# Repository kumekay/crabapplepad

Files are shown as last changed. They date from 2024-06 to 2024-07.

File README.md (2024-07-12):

# crabapplepad v2

Wireless minimalistic foldable split keyboard

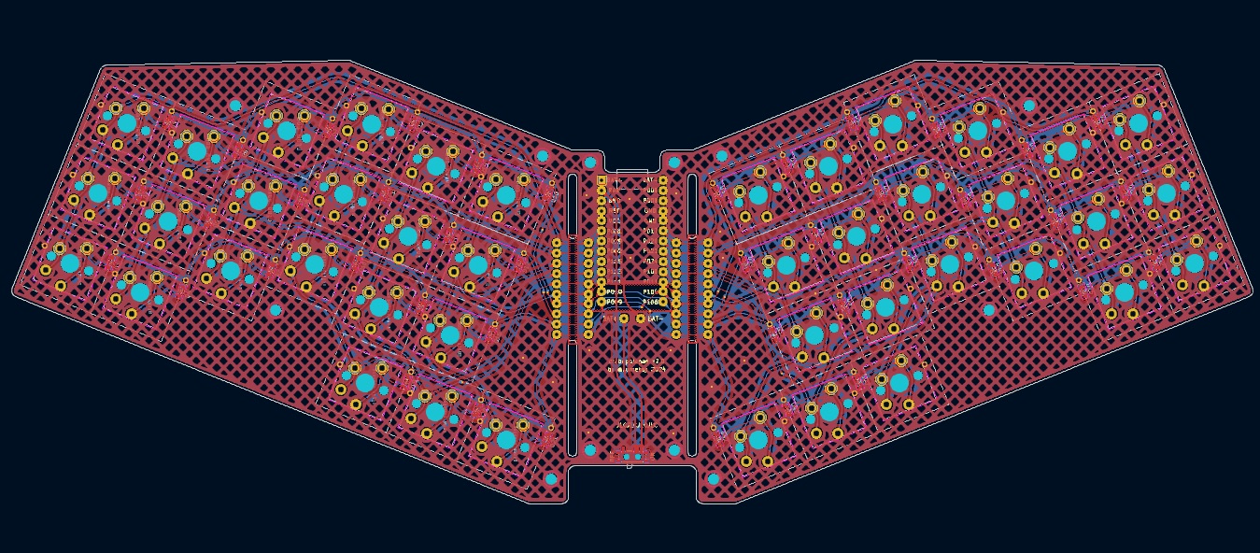
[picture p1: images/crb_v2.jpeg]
crabapplepad v2


## Features

- Supports Kailh Choc and MX switches
- Optionally foldable with Choc switches
- Minimalistic. No LEDs, no RGB, no extra keys
- With Kailh Choc it's 3cm thick in the folded state
- Split. The two halves are connected with a 3d printed hinge
- Wireless. Uses Nice!Nano or ProMicro nRF52840 with BLE
- 42 keys (I use Cyrillic layout too and 36 keys is not enough)
- Apple Magic Trackpad can be magnetically attached (optional)

## PCB design

PCB is generated using [ergogen](https://github.com/ergogen/ergogen). Then it finished in KiCAD.
To regenerate the PCB run:

```bash
npx ergogen . --clean && open output/pcbs/kbd.kicad_pcb
```

NB! The final PCB was heavily modified in KiCAD

## Firmware

The firmware is based on [ZMK](https://zmkfirmware.dev/) and [Myrioku Layout](https://github.com/manna-harbour/miryoku) adapted for 42 keys. T

## Where is the slim V1?

It's in the [v1](https://github.com/kumekay/crabapplepad/tree/v1) branch. The V1 is ccm thick in the folded state with Kailh X switches. The V2 is 3cm thick with Kailh Choc switches.

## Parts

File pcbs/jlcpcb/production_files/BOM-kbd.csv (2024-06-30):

Comment | Designator | Footprint | LCSC
SW_MX_Choc_PCB_1.00u | S42 | SW_Cherry_MX_Choc_PCB_1.00u_nosilk
SW_MX_Choc_PCB_1.00u | S37 | SW_Cherry_MX_Choc_PCB_1.00u_nosilk
SW_MX_Choc_PCB_1.00u | S14 | SW_Cherry_MX_Choc_PCB_1.00u_nosilk
SW_MX_Choc_PCB_1.00u | S8 | SW_Cherry_MX_Choc_PCB_1.00u_nosilk
SW_MX_Choc_PCB_1.00u | S4 | SW_Cherry_MX_Choc_PCB_1.00u_nosilk
SW_MX_Choc_PCB_1.00u | S16 | SW_Cherry_MX_Choc_PCB_1.00u_nosilk
SW_MX_Choc_PCB_1.00u | S6 | SW_Cherry_MX_Choc_PCB_1.00u_nosilk
SW_MX_Choc_PCB_1.00u | S26 | SW_Cherry_MX_Choc_PCB_1.00u_nosilk
SW_MX_Choc_PCB_1.00u | S20 | SW_Cherry_MX_Choc_PCB_1.00u_nosilk
SW_MX_Choc_PCB_1.00u | S15 | SW_Cherry_MX_Choc_PCB_1.00u_nosilk
SW_MX_Choc_PCB_1.00u | S17 | SW_Cherry_MX_Choc_PCB_1.00u_nosilk
SW_MX_Choc_PCB_1.00u | S29 | SW_Cherry_MX_Choc_PCB_1.00u_nosilk
SW_MX_Choc_PCB_1.00u | S21 | SW_Cherry_MX_Choc_PCB_1.00u_nosilk
SW_MX_Choc_PCB_1.00u | S31 | SW_Cherry_MX_Choc_PCB_1.00u_nosilk
SW_MX_Choc_PCB_1.00u | S12 | SW_Cherry_MX_Choc_PCB_1.00u_nosilk
SW_MX_Choc_PCB_1.00u | S25 | SW_Cherry_MX_Choc_PCB_1.00u_nosilk
SW_MX_Choc_PCB_1.00u | S13 | SW_Cherry_MX_Choc_PCB_1.00u_nosilk
SW_MX_Choc_PCB_1.00u | S34 | SW_Cherry_MX_Choc_PCB_1.00u_nosilk
SW_MX_Choc_PCB_1.00u | S23 | SW_Cherry_MX_Choc_PCB_1.00u_nosilk
SW_MX_Choc_PCB_1.00u | S7 | SW_Cherry_MX_Choc_PCB_1.00u_nosilk
SW_MX_Choc_PCB_1.00u | S11 | SW_Cherry_MX_Choc_PCB_1.00u_nosilk
SW_MX_Choc_PCB_1.00u | S24 | SW_Cherry_MX_Choc_PCB_1.00u_nosilk
SW_MX_Choc_PCB_1.00u | S39 | SW_Cherry_MX_Choc_PCB_1.00u_nosilk
SW_MX_Choc_PCB_1.00u | S10 | SW_Cherry_MX_Choc_PCB_1.00u_nosilk
SW_MX_Choc_PCB_1.00u | S35 | SW_Cherry_MX_Choc_PCB_1.00u_nosilk
SW_MX_Choc_PCB_1.00u | S2 | SW_Cherry_MX_Choc_PCB_1.00u_nosilk
SW_MX_Choc_PCB_1.00u | S18 | SW_Cherry_MX_Choc_PCB_1.00u_nosilk
SW_MX_Choc_PCB_1.00u | S36 | SW_Cherry_MX_Choc_PCB_1.00u_nosilk
SW_MX_Choc_PCB_1.00u | S1 | SW_Cherry_MX_Choc_PCB_1.00u_nosilk
SW_MX_Choc_PCB_1.00u | S28 | SW_Cherry_MX_Choc_PCB_1.00u_nosilk
SW_MX_Choc_PCB_1.00u | S3 | SW_Cherry_MX_Choc_PCB_1.00u_nosilk
SW_MX_Choc_PCB_1.00u | S19 | SW_Cherry_MX_Choc_PCB_1.00u_nosilk
SW_MX_Choc_PCB_1.00u | S33 | SW_Cherry_MX_Choc_PCB_1.00u_nosilk
SW_MX_Choc_PCB_1.00u | S9 | SW_Cherry_MX_Choc_PCB_1.00u_nosilk
SW_MX_Choc_PCB_1.00u | S30 | SW_Cherry_MX_Choc_PCB_1.00u_nosilk
SW_MX_Choc_PCB_1.00u | S40 | SW_Cherry_MX_Choc_PCB_1.00u_nosilk
SW_MX_Choc_PCB_1.00u | S41 | SW_Cherry_MX_Choc_PCB_1.00u_nosilk
SW_MX_Choc_PCB_1.00u | S32 | SW_Cherry_MX_Choc_PCB_1.00u_nosilk
SW_MX_Choc_PCB_1.00u | S27 | SW_Cherry_MX_Choc_PCB_1.00u_nosilk
SW_MX_Choc_PCB_1.00u | S38 | SW_Cherry_MX_Choc_PCB_1.00u_nosilk
SW_MX_Choc_PCB_1.00u | S22 | SW_Cherry_MX_Choc_PCB_1.00u_nosilk
SW_MX_Choc_PCB_1.00u | S5 | SW_Cherry_MX_Choc_PCB_1.00u_nosilk
 | D15 | D_SOD-323_HandSoldering
 | D30 | D_SOD-323_HandSoldering
 | D3 | D_SOD-323_HandSoldering
 | D5 | D_SOD-323_HandSoldering
 | D18 | D_SOD-323_HandSoldering
 | D13 | D_SOD-323_HandSoldering
 | D17 | D_SOD-323_HandSoldering
 | D28 | D_SOD-323_HandSoldering
 | D35 | D_SOD-323_HandSoldering
 | D39 | D_SOD-323_HandSoldering
 | D27 | D_SOD-323_HandSoldering
 | D11 | D_SOD-323_HandSoldering
 | D41 | D_SOD-323_HandSoldering
 | D25 | D_SOD-323_HandSoldering
 | D23 | D_SOD-323_HandSoldering
 | D32 | D_SOD-323_HandSoldering
 | D20 | D_SOD-323_HandSoldering
 | MCU1 | ProMicro
 | D14 | D_SOD-323_HandSoldering
 | D40 | D_SOD-323_HandSoldering
 | D21 | D_SOD-323_HandSoldering
 | D7 | D_SOD-323_HandSoldering
 | D16 | D_SOD-323_HandSoldering
 | D1 | D_SOD-323_HandSoldering
 | D31 | D_SOD-323_HandSoldering
 | D6 | D_SOD-323_HandSoldering
 | D42 | D_SOD-323_HandSoldering
 | D29 | D_SOD-323_HandSoldering
 | D10 | D_SOD-323_HandSoldering
 | D8 | D_SOD-323_HandSoldering
 | D26 | D_SOD-323_HandSoldering
 | D24 | D_SOD-323_HandSoldering
 | D2 | D_SOD-323_HandSoldering
 | D4 | D_SOD-323_HandSoldering
 | D19 | D_SOD-323_HandSoldering
 | D22 | D_SOD-323_HandSoldering
 | D37 | D_SOD-323_HandSoldering
 | D36 | D_SOD-323_HandSoldering
 | D33 | D_SOD-323_HandSoldering
 | D12 | D_SOD-323_HandSoldering
 | D9 | D_SOD-323_HandSoldering
 | D34 | D_SOD-323_HandSoldering
 | D38 | D_SOD-323_HandSoldering

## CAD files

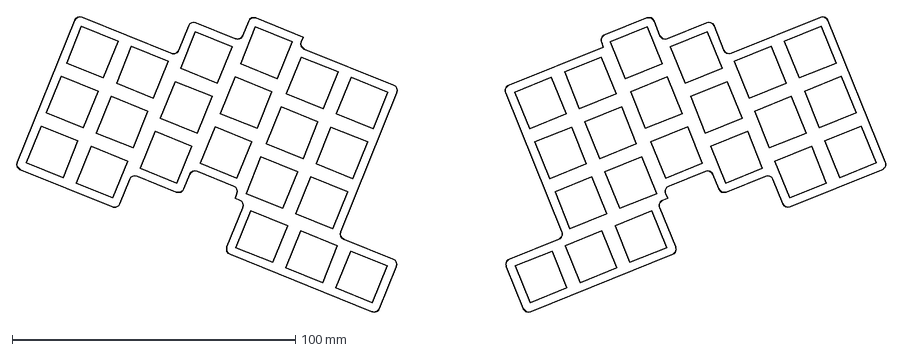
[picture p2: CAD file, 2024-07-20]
outlines/key_holder_choc.dxf
307.0 x 104.7 mm

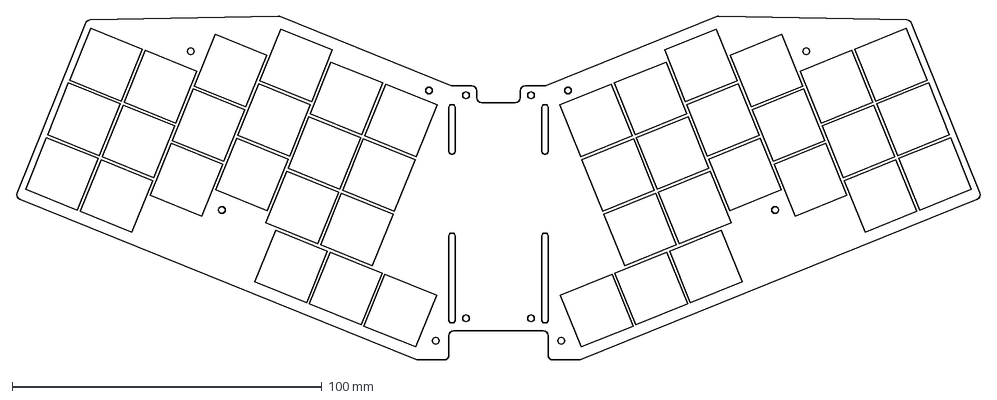
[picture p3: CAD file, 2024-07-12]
outlines/combo.dxf
311.4 x 111.0 mm

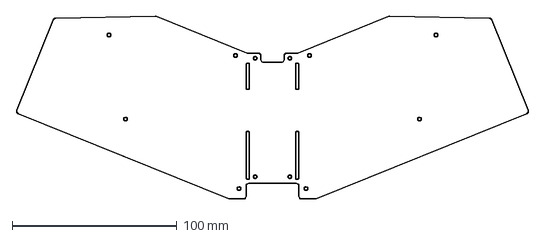
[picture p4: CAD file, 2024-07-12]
outlines/board.dxf
311.4 x 111.0 mm

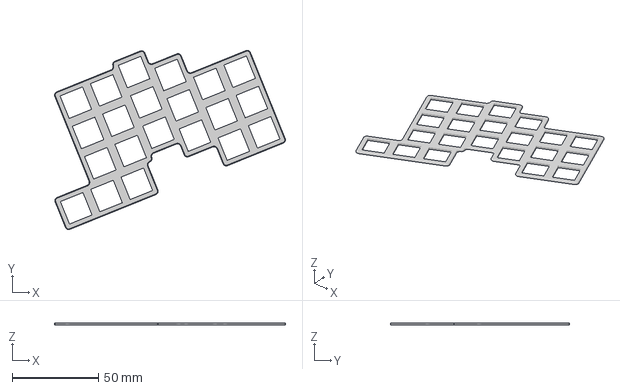
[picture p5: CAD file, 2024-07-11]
outlines/Key holder.3mf
134.3 x 104.2 x 1.40 mm

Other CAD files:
outlines/key_holder.dxf

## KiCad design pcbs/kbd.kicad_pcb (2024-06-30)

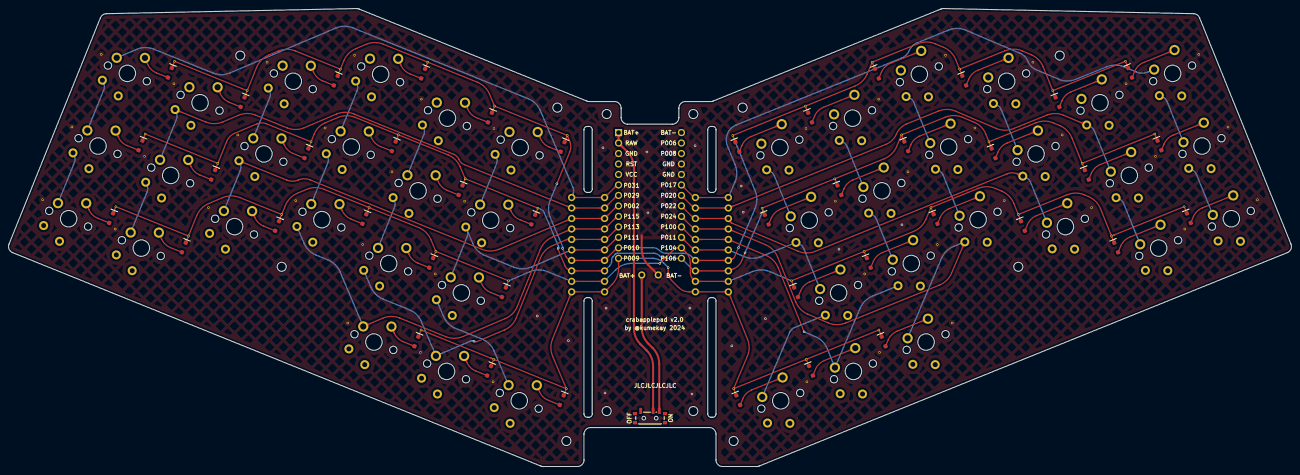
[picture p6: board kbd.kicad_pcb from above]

Board: 2 copper layers, 311.0 x 111.0 mm, 98 parts (0 on the bottom side), 60 nets.

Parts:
D1, D2, D3, D4, D5, D6, D7, D8, D9, D10, D11, D12, D13, D14, D15, D16, D17, D18, D19, D20, D21, D22, D23, D24, D25, D26, D27, D28, D29, D30, D31, D32, D33, D34, D35, D36, D37, D38, D39, D40, D41, D42: D_SOD-323_HandSoldering
MCU1: ProMicro
PWR1: power_switch_smd_side
S1, S2, S3, S4, S5, S6, S7, S8, S9, S10, S11, S12, S13, S14, S15, S16, S17, S18, S19, S20, S21, S22, S23, S24, S25, S26, S27, S28, S29, S30, S31, S32, S33, S34, S35, S36, S37, S38, S39, S40, S41, S42: SW_MX_Choc_PCB_1.00u; SW_Cherry_MX_Choc_PCB_1.00u_nosilk
_129, _130, _131, _132, _133, _134, _135, _136, _137, _138, _139, _140: MountingHole_2.2mm_M2_DIN965

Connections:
GND: MCU1.3, MCU1.14, MCU1.17, MCU1.18
P002: MCU1.8, S7.1, S8.1, S9.1
P009: D19.1, D20.1, D21.1, D40.1, D41.1, D42.1, MCU1.13
P010: D3.1, D6.1, D9.1, D12.1, D15.1, D18.1, D24.1, D27.1, D30.1, D33.1, D36.1, D39.1, MCU1.12
P011: MCU1.24, S37.1, S38.1, S39.1, S42.1
P017: MCU1.19, S22.1, S23.1, S24.1
P020: MCU1.20, S25.1, S26.1, S27.1
P022: MCU1.21, S28.1, S29.1, S30.1
P024: MCU1.22, S31.1, S32.1, S33.1, S40.1
P029: MCU1.7, S4.1, S5.1, S6.1
P031: MCU1.6, S1.1, S2.1, S3.1
P100: MCU1.23, S34.1, S35.1, S36.1, S41.1
P104: D1.1, D4.1, D7.1, D10.1, D13.1, D16.1, D22.1, D25.1, D28.1, D31.1, D34.1, D37.1, MCU1.25
P106: D2.1, D5.1, D8.1, D11.1, D14.1, D17.1, D23.1, D26.1, D29.1, D32.1, D35.1, D38.1, MCU1.26
P111: MCU1.11, S16.1, S17.1, S18.1, S21.1
P113: MCU1.10, S13.1, S14.1, S15.1, S20.1
P115: MCU1.9, S10.1, S11.1, S12.1, S19.1
RAW: MCU1.1, MCU1.2, PWR1.2
alpha_cluster: D19.2, S19.2
beta_cluster: D20.2, S20.2
gamma_cluster: D21.2, S21.2
index_bottom: D13.2, S13.2
index_home: D14.2, S14.2
index_top: D15.2, S15.2
inner_bottom: D16.2, S16.2
inner_home: D17.2, S17.2
inner_top: D18.2, S18.2
middle_bottom: D10.2, S10.2
middle_home: D11.2, S11.2
middle_top: D12.2, S12.2
mirror_alpha_cluster: D40.2, S40.2
mirror_beta_cluster: D41.2, S41.2
mirror_gamma_cluster: D42.2, S42.2
mirror_index_bottom: D34.2, S34.2
mirror_index_home: D35.2, S35.2
mirror_index_top: D36.2, S36.2
mirror_inner_bottom: D37.2, S37.2
mirror_inner_home: D38.2, S38.2
mirror_inner_top: D39.2, S39.2
mirror_middle_bottom: D31.2, S31.2
mirror_middle_home: D32.2, S32.2
mirror_middle_top: D33.2, S33.2
mirror_outer_bottom: D22.2, S22.2
mirror_outer_home: D23.2, S23.2
mirror_outer_top: D24.2, S24.2
mirror_pinky_bottom: D25.2, S25.2
mirror_pinky_home: D26.2, S26.2
mirror_pinky_top: D27.2, S27.2
mirror_ring_bottom: D28.2, S28.2
mirror_ring_home: D29.2, S29.2
mirror_ring_top: D30.2, S30.2
outer_bottom: D1.2, S1.2
outer_home: D2.2, S2.2
outer_top: D3.2, S3.2
pinky_bottom: D4.2, S4.2
pinky_home: D5.2, S5.2
pinky_top: D6.2, S6.2
ring_bottom: D7.2, S7.2
ring_home: D8.2, S8.2
ring_top: D9.2, S9.2

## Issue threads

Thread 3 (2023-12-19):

Power consumption is too high

kumekay, 2023-12-19:
Because it's true wireless, the left half constantly listens for the right one. As a result, with a 130mAh battery, the left half only lasts about 4 days.

Ways to mitigate:
- proper sleep when unused (power switch?)
- Make the halves wire connected

ryanwwest, 2025-07-02:
By the way, I had 'solved' this previously by having a third zmk dongle device plugged directly into the computer acting as the Bluetooth master, and each keyboard split side as a slave. Both last way way longer now and have a very reliable connection, at the expense of a dongle. I'm curious if somehow you overcame the issues of master connection to laptop and battery another way in the new single mcu layout.

kumekay, 2025-07-02:
Because there is only one controller it acts as a slave, so no issue at all - and halves are connected with a flex cable.

And now ZMK supports UART Split https://zmk.dev/docs/features/split-keyboards#full-duplex-wired-uart for wired 2-mcu design.

ryanwwest, 2025-07-02:
Excellent. I hope people start making ZMK wireless Ploopys/trackball mice soon too!

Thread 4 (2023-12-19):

Kailh X switches are unreliable

kumekay, 2023-12-19:
- Sometimes they just die randomly
- Keycaps are crappy

Ideas:

- Switch to Choc
- Keep choc pressed in folded position (too much pressure?)

ryanwwest, 2024-03-30:
Chocs are nice, perhaps would feel nicer to type on as well, a bit more mechanical. Sure, it might be slightly thicker but still super portable.

Honestly I think your design is spectacular. If you're planning to add in Choc (and if qmk wired could work, since I feel like the zmk BLE/battery are just unreliable after owning several splits), I'd totally consider buying one if that were an option.

kumekay, 2024-04-01:
@ryanwwest  Hi Ryan, thank you for the appreciation of my design,

I'm planning to make a new iteration with CHOC switches and better work-on-laps rigidity.

I'm also planning to use a single MCU in the hinge and a couple of custom FPCs to connect the halves. First it will less power hungry with ZMK and still can be used with QMK.

I do not have any time estimates, but likely it will happen this summer. I'll keep this repo updated.

BTW, the GPD device is super cool, but I wanted something similar with macOS, so made a home-grown solution https://hackaday.io/project/193037-macbleth-macos-tablet

ryanwwest, 2024-04-01:
That's great to hear. I've heard similar reliability issues with the Choc Mini switches so you may want to avoid, but the regular Chocs are great.

A single MCU sounds great, no need for split wireless if they're always in the case which I've always had work-stopping issues with.

I'm excited to see what you come up with. Macbleth is also really cool!

kumekay, 2025-07-01:
My best effort on the topic is https://github.com/kumekay/aronia

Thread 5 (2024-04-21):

Provide Case STL files

heynest, 2024-04-21:
### User Story
**As a** re-creator
**I want to** download STL files for the case
**So that** I do not need to by a Fusion license (which costs at least 96 €)

Currently, I cannot "just" print the case but I need to get fusion first (as far as I see).

kumekay, 2024-04-21:
Hello @heynest

Thank you for the interest

I don't have my laptop with me, but you can use Fusion for free https://www.autodesk.com/products/fusion-360/personal

BTW, I'm planning a new iteration of the keyboard this summer with a few flaws fixed (but it will be a bit thicker)

heynest, 2024-04-21:
Thanks for your quick reaction and the hint for autodesk!

Well, actually, I do not want to rebuild it as you may think. I like the idea of having a foldable and expandablre base to which I can mount my ZSA Voyager (magnetically) when I need to go to a meeting room...
I wanted to have the STL files to understand how you built the mechanism...

Thanks for sharing.

kumekay, 2024-04-22:
It's a simple hinge with a thin steel wire inside:

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

STLs: [Archive.zip](https://github.com/kumekay/crabapplepad/files/15061328/Archive.zip)

Closed 2024-05-06.

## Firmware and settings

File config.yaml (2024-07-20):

meta:
  engine: 4.1.0
  name: crabapplepad
  version: 2.0
  author: kumekay
  url: https://github.com/kumekay/crabapplepad/tree/v2

units:
  # Keycap
  krx: 18 # Keycap raw width
  kry: 18 # Keycap raw height
  po: 1.6 # Offset between keycaps and outline

  # Keycap spacing
  kx: 19
  ky: 19

  sd: 2.2 # Screw diameter
  ps: 2.54 # Pin spacing

  # MCU
  pos: -20 - 8.7ps # Hole offset from bottom pin

points:
  zones:
    matrix:
      anchor:
        shift: [100, -100]
      key:
        padding: 1ky
        spread: 1kx
        tags:
      columns:
        outer:
          key:
            column_net: P031
            mirror.column_net: P017
        pinky:
          key:
            splay: 0
            column_net: P029
            mirror.column_net: P020
        ring:
          key:
            stagger: 0.7ky
            column_net: P002
            mirror.column_net: P022
        middle:
          key:
            stagger: 0.5ky
            column_net: P115
            mirror.column_net: P024
        index:
          key:
            stagger: -0.2ky
            column_net: P113
            mirror.column_net: P100
        inner:
          key:
            column_net: P111
            mirror.column_net: P011
      rows:
        bottom:
          row_net: P104
          mirror.row_net: P104
        home:
          row_net: P106
          mirror.row_net: P106
        top:
          row_net: P010
          mirror.row_net: P010
    thumbs:
      key:
        padding: 1ky
        spread: 1kx
      anchor:
        ref: matrix_middle_bottom
        shift: [1.2kx, -1.2ky]
      columns:
        alpha:
          key:
            column_net: P115
            mirror.column_net: P024
        beta:
          key:
            column_net: P113
            mirror.column_net: P100
        gamma:
          key:
            column_net: P111
            mirror.column_net: P011
      rows:
        cluster:
          row_net: P009
          mirror.row_net: P009

  rotate: -22
  mirror: &mirror
    ref: matrix_inner_home
    distance: 74 + 2po
outlines:
  _keys:
    - what: rectangle
      where: true
      size: [krx, kry]

  board:
    - what: polygon
      operation: add
      fillet: po
      points:
        - ref: matrix_outer_top
          shift: [-0.5kx-po, 0.5ky+1po]
        - ref: matrix_middle_top
          shift: [-0.5kx-po, 0.5ky+2po]
        - ref: matrix_inner_top
          shift: [0.5kx+po, 0.7ky+2po]
        - ref: mirror_matrix_inner_top
          shift: [0.5kx+po, 0.7ky+2po]
        - ref: mirror_matrix_middle_top
          shift: [-0.5kx-po, 0.5ky+2po]
        - ref: mirror_matrix_outer_top
          shift: [-0.5kx-po, 0.5ky+1po]
        - ref: mirror_matrix_outer_bottom
          shift: [-0.5kx-po, -0.5ky-2po]
        - ref: mirror_thumbs_gamma_cluster
          shift: [0.5kx + po, -0.5ky-2po]
        - ref: thumbs_gamma_cluster
          shift: [0.5kx + po, -0.5ky-2po]
        - ref: matrix_outer_bottom
          shift: [-0.5kx-po, -0.5ky-2po]

    # USB cutout
    - what: rectangle
      operation: subtract
      where:
        ref.aggregate.parts: [matrix_index_top, mirror_matrix_index_top]
        shift: [0, ps]
      size: [14, 8]
      fillet: po

    # Left top cutout
    - what: rectangle
      operation: subtract
      where:
        ref.aggregate.parts: [matrix_index_top, mirror_matrix_index_top]
        shift: [-15, -10]
      size: [2, 16]
      fillet: .8

    # Right top cutout
    - what: rectangle
      operation: subtract
      where:
        ref.aggregate.parts: [matrix_index_top, mirror_matrix_index_top]
        shift: [15, -10]
      size: [2, 16]
      fillet: .8

    # Left bottom cutout
    - what: rectangle
      operation: subtract
      where:
        ref.aggregate.parts: [matrix_index_top, mirror_matrix_index_top]
        shift: [-15, -58]
      size: [2, 29]
      fillet: .8

    # Right bottom cutout
    - what: rectangle
      operation: subtract
      where:
        ref.aggregate.parts: [matrix_index_top, mirror_matrix_index_top]
        shift: [15, -58]
      size: [2, 29]
      fillet: .8

    # Bottom cutout
    - what: rectangle
      operation: subtract
      where:
        ref.aggregate.parts: [matrix_index_top, mirror_matrix_index_top]
        shift: [0, -90]
      size: [32, 30]
      fillet:
        po

        # Mount holes

    - what: circle
      operation: subtract
      radius: 1.1
      where:
        ref.aggregate.parts: [matrix_index_top, mirror_matrix_index_top]
        shift: [-10.5, 1]

    - what: circle
      operation: subtract
      radius: 1.1
      where:
        ref.aggregate.parts: [matrix_index_top, mirror_matrix_index_top]
        shift: [10.5, 1]

    - what: circle
      operation: subtract
      radius: 1.1
      where:
        ref.aggregate.parts: [matrix_index_top, mirror_matrix_index_top]
        shift: [-10.5, -71]
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

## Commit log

2023-05-08 Add mount holes
2023-05-09 Add switch footprint
2023-05-15 Add diodes and MCU
2023-05-27 Redo mounting holes
2023-05-29 change magnet position
2023-05-31 Update mounting holes
2023-05-31 Add pin labels
2023-05-31 Adjust sliding slot
2023-06-04 Add the PCB
    [board.dxf, combo.dxf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]
2023-10-02 Add case files and update README
    [key frame.f3d]
2024-06-22 feat: Draft of V2
    [case.f3d, key frame.f3d]
2024-06-23 feat: add diodes and pins
2024-06-25 fix: mout holes
2024-06-27 feat: add power switch
2024-06-27 feat: add new kicad project
    [board.dxf, combo.dxf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]
2024-06-29 feat: wip version of the board
    [kbd.kicad_pcb]
2024-06-29 feat: v2 production files
    [bom.csv, designators.csv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]
2024-06-30 fix: Update production files
    [BOM-kbd.csv, bom.csv, designators.csv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]
2024-07-11 feat: add keyholder 3d model
    [Key holder.3mf, key_holder.dxf]
2024-07-12 refactor: move out of hw keyboard
    [BOM-kbd.csv, Key holder.3mf, board.dxf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]
2024-07-12 feat: add mount holes to outlines
    [board.dxf, combo.dxf]
2024-07-20 feat: Add keyholder for choc
    [key_holder_choc.dxf]
